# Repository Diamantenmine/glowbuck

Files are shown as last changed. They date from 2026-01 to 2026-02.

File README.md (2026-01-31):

# glowbuck
Glowbuck is a voltage converter and control board that allows you to power addressable LED strips with USB-C PD.

Together with [Firefly Luciferin](https://github.com/sblantipodi/firefly_luciferin), you can create your own ambilight that connects via USB-C to your computer and draws power from a USB-C PD power supply. Glowbuck is in no way associated with the linked project.


The left USB-C socket is used for data. The right socket shall be connected to a suitable USB-C PD supply. The spring-loaded connection terminal allows easy and safe connection to a 5 V addressable LED strip with, for example, SK6812 or WS2812B. The output current is measured with a 2 mOhm shunt. A shunt amplifier allows the integrated ESP32 S3 to measure the current flow and shut down the buck regulator when an unusually large current is detected.

## Quick Facts:
- Output: 5 V @ 10 A
- Input: 20 V @ 3 A. Via I2C, the microcontroller can reconfigure the PD controller and negotiate other voltage and current requirements for the input.
- Microcontroller: ESP32 S3
- Output current measurement with an integrated shunt

## Warning and Disclaimer

**Warning**: This project is in a alpha state and the hardware has not yet been tested.

This project is provided "as is" without warranty of any kind, either expressed or implied. The author makes no guarantees regarding the functionality, reliability, or suitability of this project for any particular purpose.
By using this project, you acknowledge and agree that:
- No liability is accepted for any damages, losses, or issues arising from the use or inability to use this project
- There is no guarantee that this project will work as intended or work at all
- The author shall not be held responsible for any direct, indirect, incidental, or consequential damages

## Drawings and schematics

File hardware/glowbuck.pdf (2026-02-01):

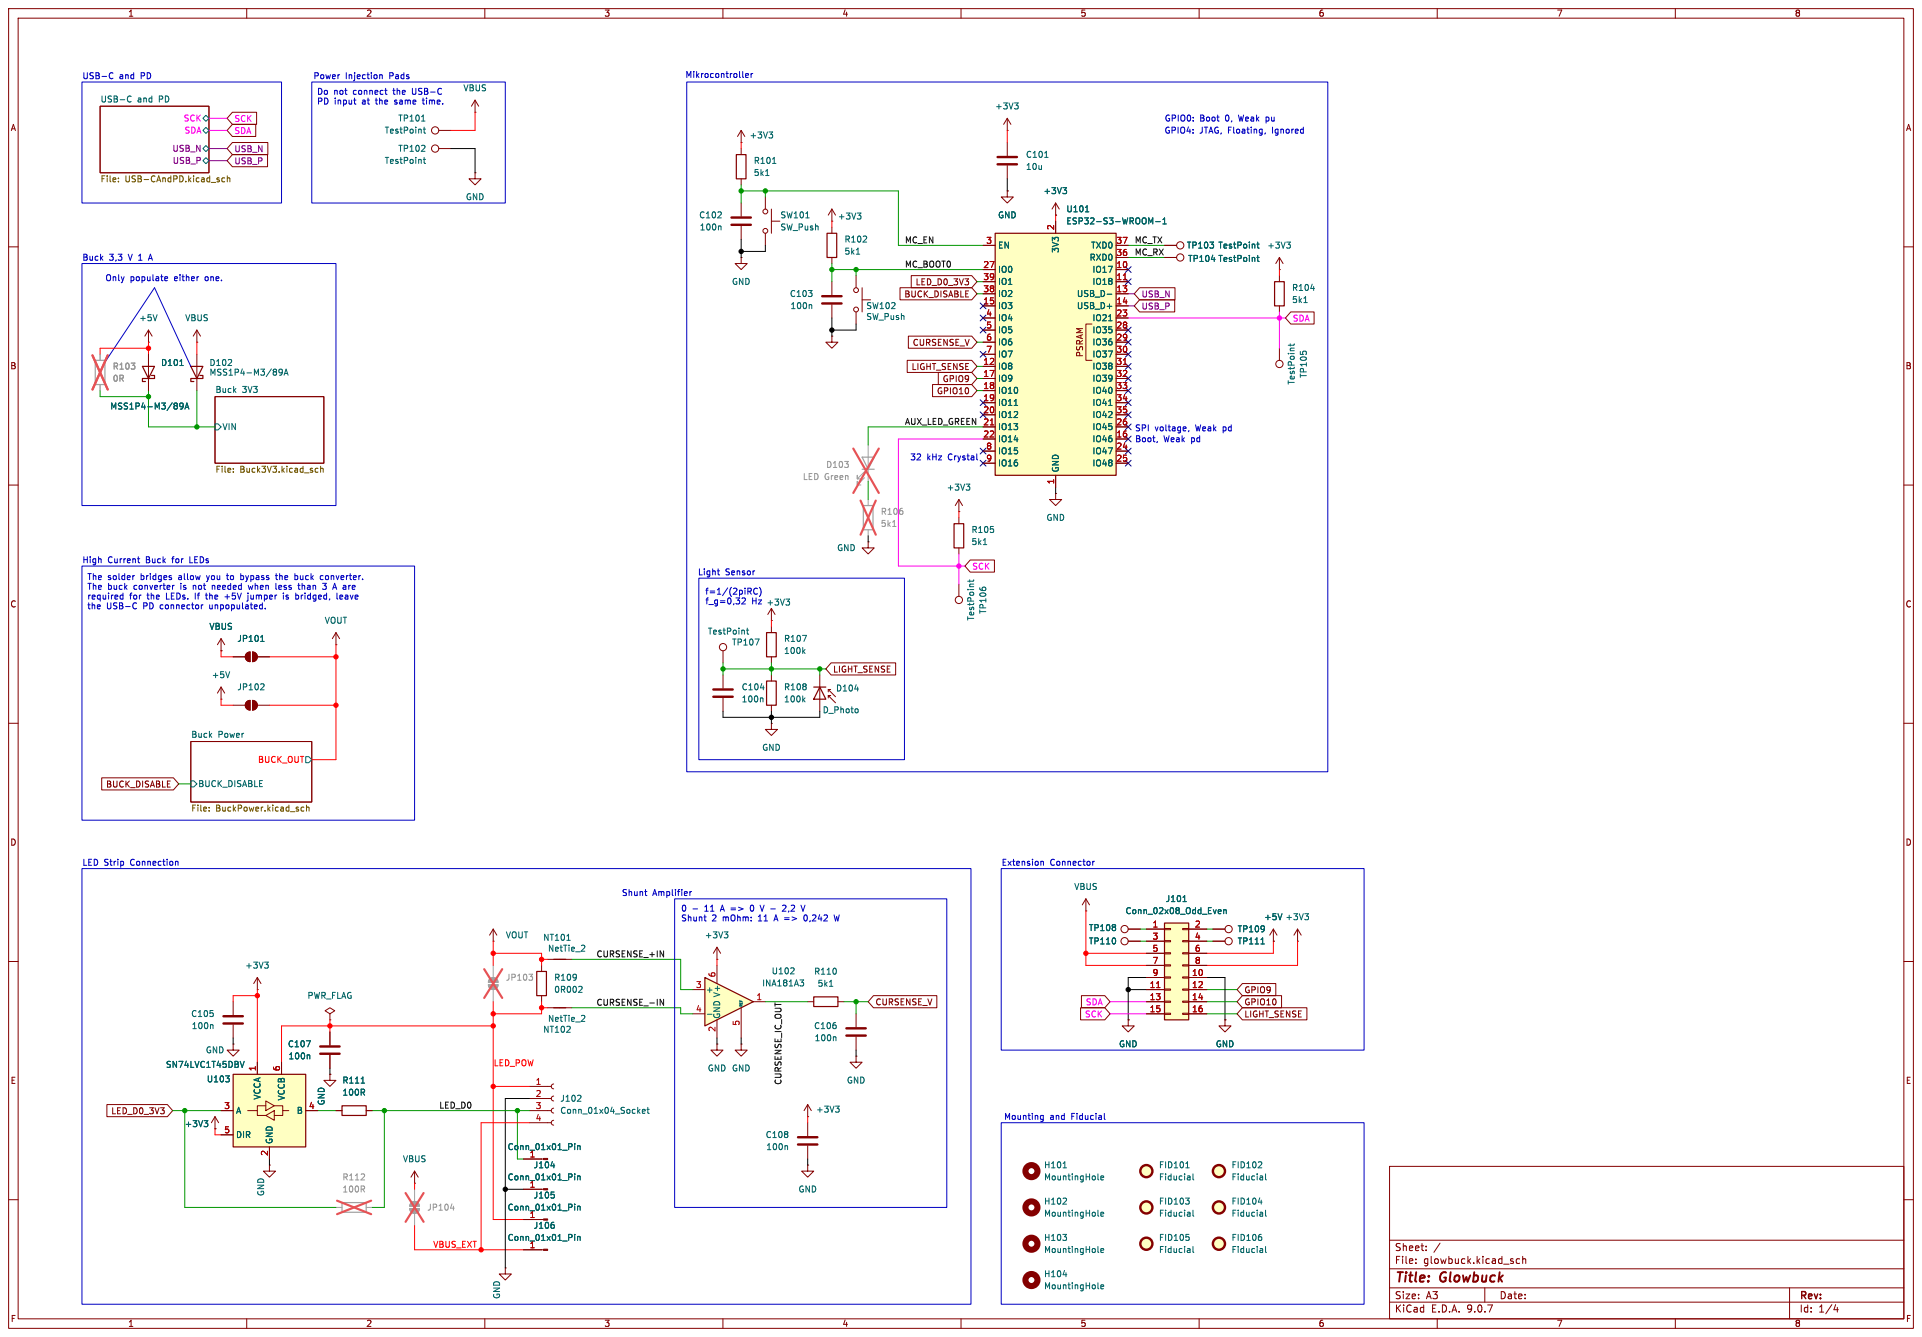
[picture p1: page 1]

File: USB-CAndPD.kicad_sch VIN

High Current Buck for LEDs

BUCK_OUT Buck Power File: BuckPower.kicad_sch

Shunt Amplifier LED Strip Connection

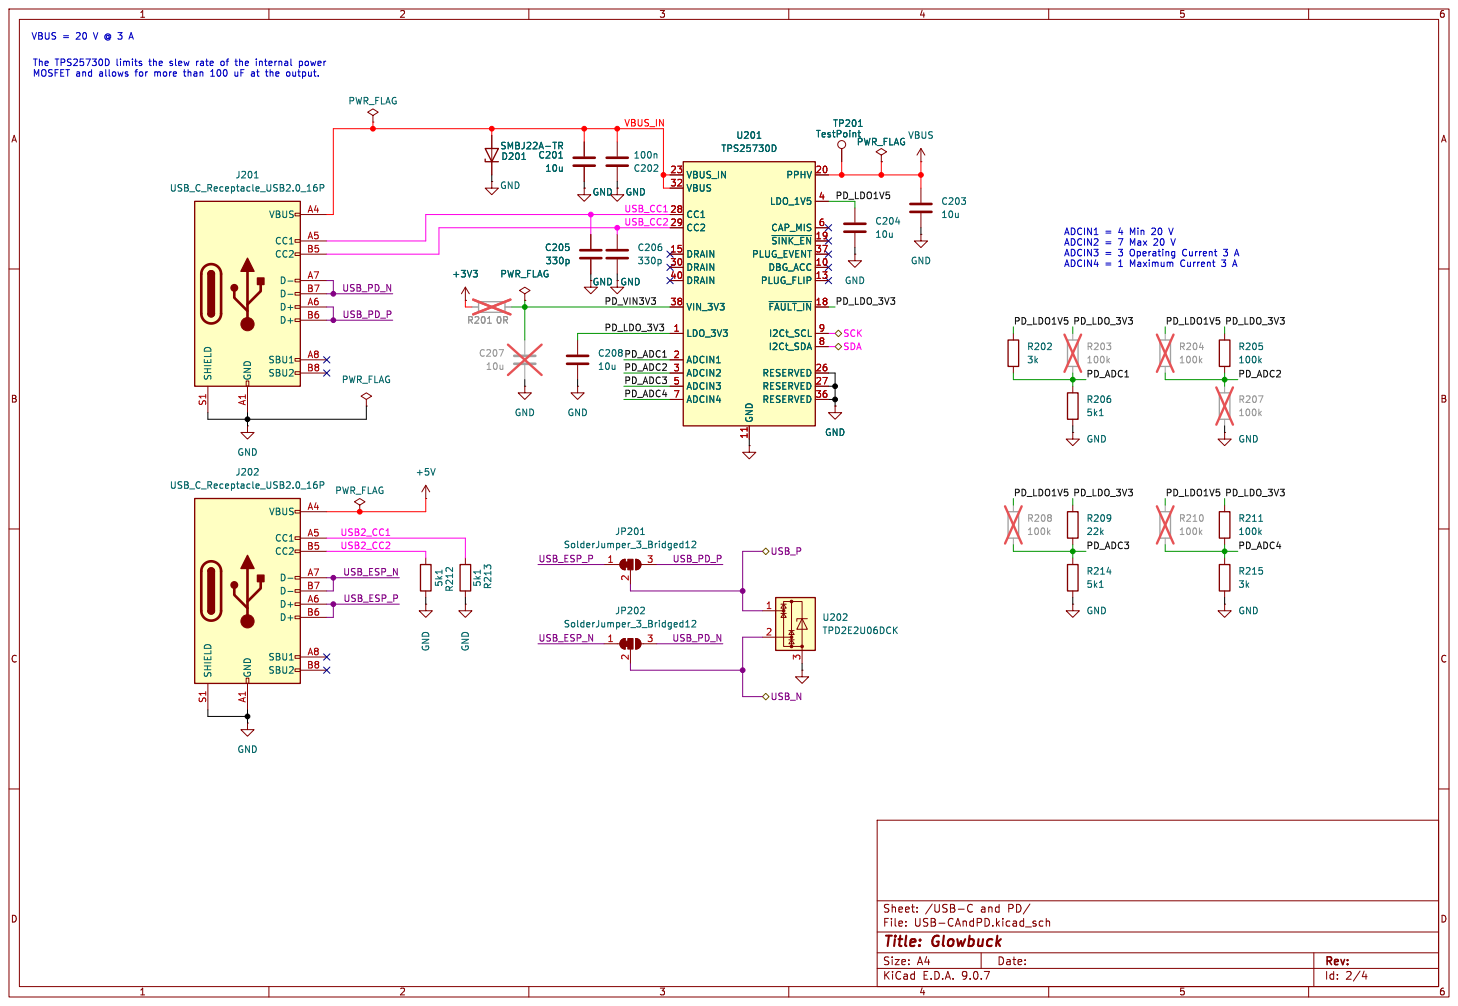
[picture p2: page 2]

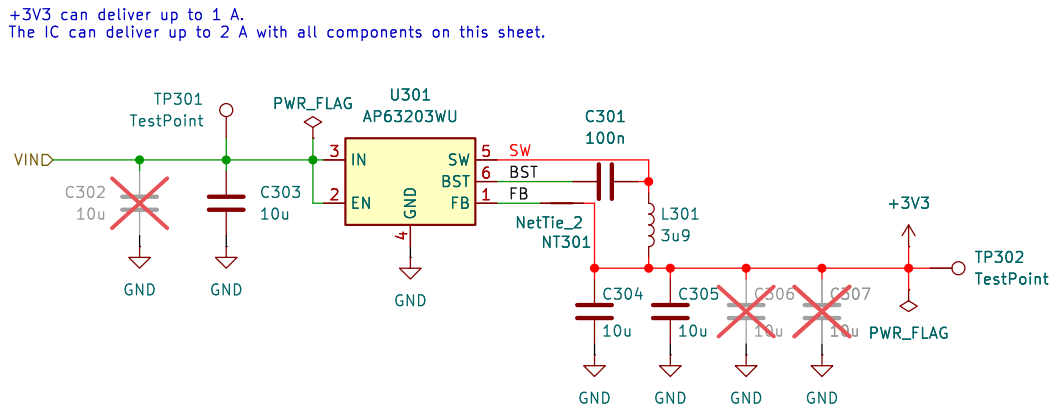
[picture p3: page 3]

4 SW 5 BST 6 FB 1 U301 AP63203WU GND GND

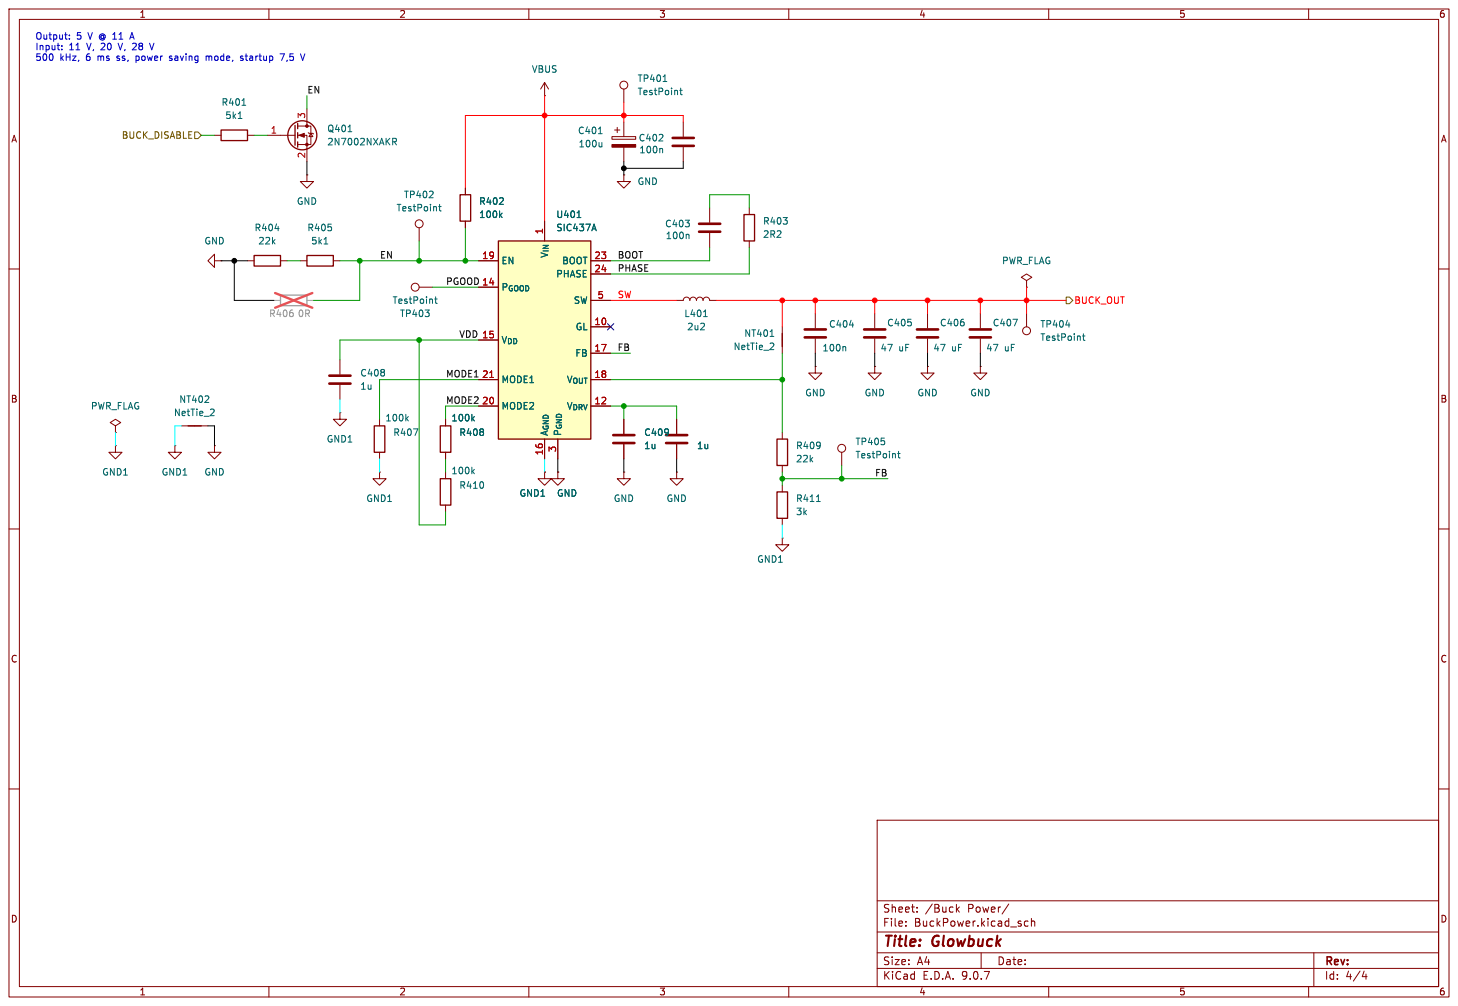
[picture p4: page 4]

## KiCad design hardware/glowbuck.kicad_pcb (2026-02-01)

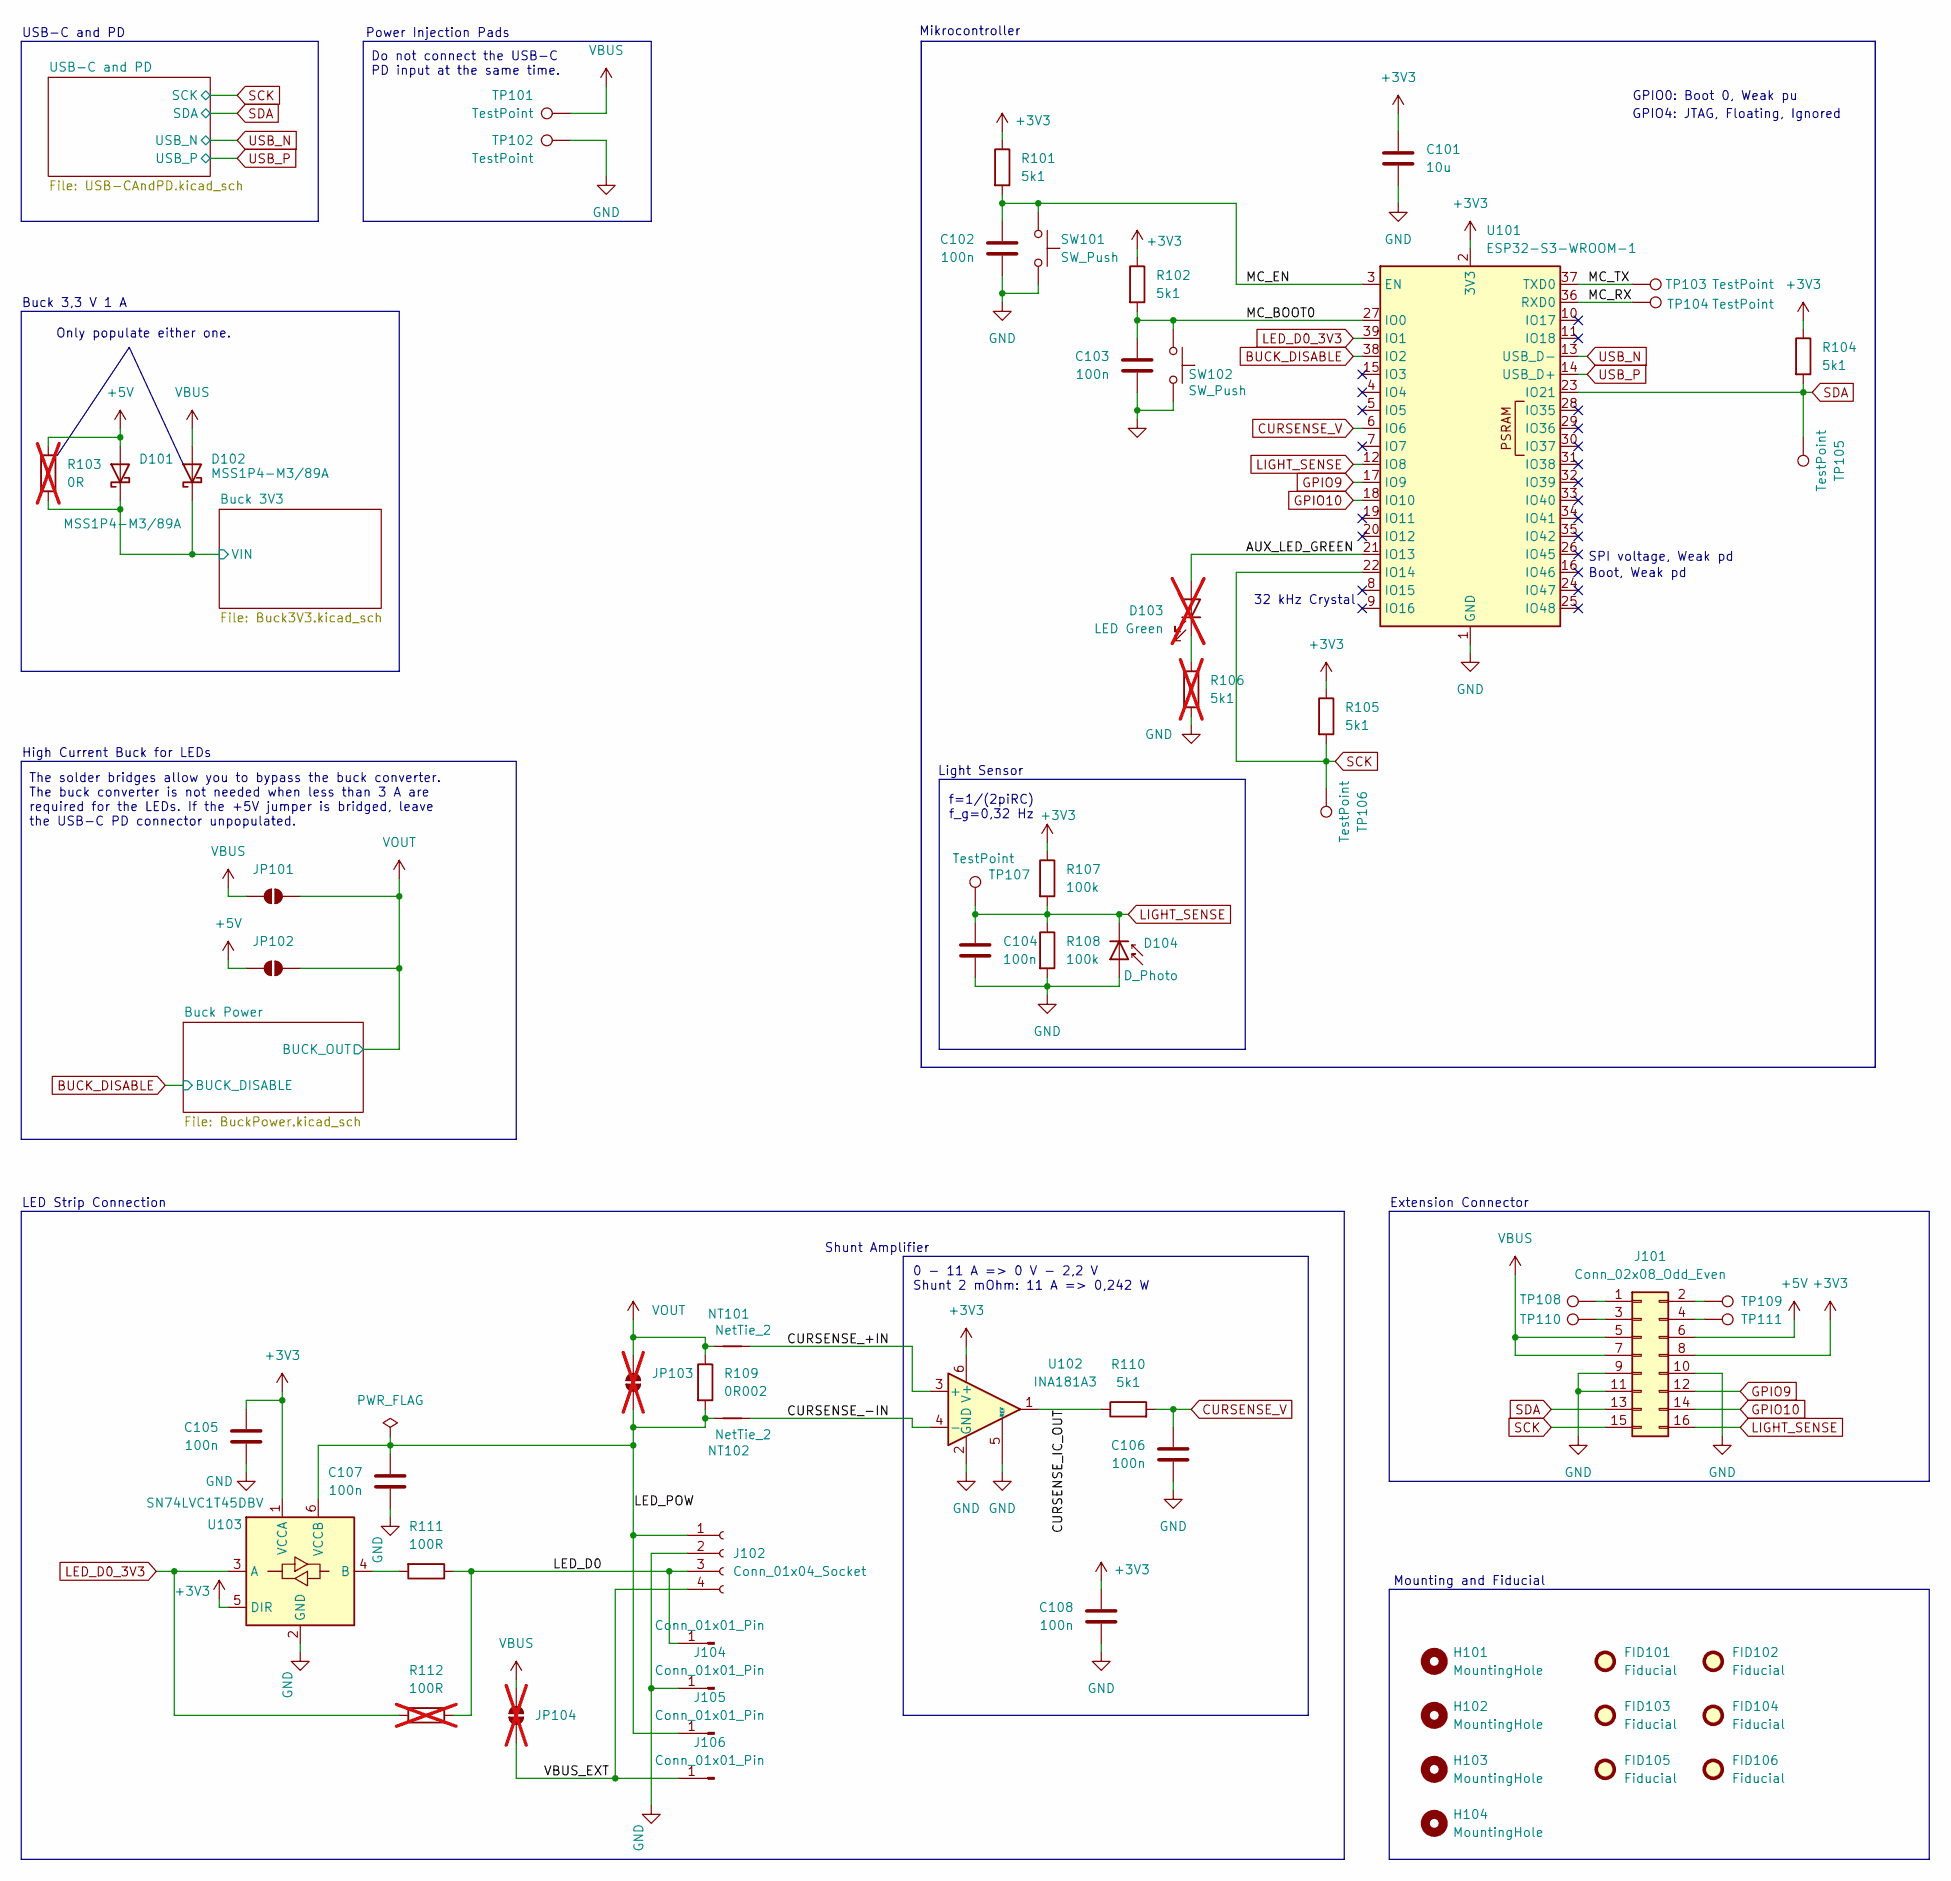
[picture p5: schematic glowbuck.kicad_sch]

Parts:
C101: 10u; C_0603_1608Metric; MouserNumber 187-CL10A106MA8NRNC
C102, C103, C104, C105, C106, C107, C108: 100n; C_0603_1608Metric; MouserNumber 187-CL10B104KB8WPND
D101, D102: MSS1P4-M3/89A; D_MicroSMP_AK; MouserNumber 625-MSS1P4-M3
D103: LED Green; LED_0603_1608Metric; MouserNumber 710-150060VS55040; not fitted
D104: D_Photo; D_1206_3216Metric; MouserNumber 743-IN-S126BTNPD
FID101, FID102, FID103, FID104, FID105, FID106: Fiducial; Fiducial_0.5mm_Mask1mm
H101, H102, H103, H104: MountingHole; MountingHole_2.2mm_M2_DIN965_Pad_TopBottom
J101: Conn_02x08_Odd_Even; PinHeader_2x08_P2.00mm_Vertical
J102: Conn_01x04_Socket; PTS 1,5_ 4-5,0-H; MouserNumber 651-1792889
J103: Conn_01x01_Pin; TestPoint_Pad_1.0x1.0mm
J104, J105, J106: Conn_01x01_Pin; TestPoint_Pad_3.0x3.0mm
JP101, JP102: SolderJumper_2_Open; SolderJumper_Open_HighCurrent
JP103, JP104: SolderJumper_2_Open; SolderJumper_Open_HighCurrent; not fitted
NT101, NT102: NetTie_2; NETTIE_0.3mm
R101, R102, R104, R105, R110: 5k1; R_0603_1608Metric; MouserNumber 603-RC0603FR-105K1L
R103: 0R; R_0603_1608Metric; MouserNumber 603-RC0603FR-130RL; not fitted
R106: 5k1; R_0603_1608Metric; MouserNumber 603-RC0603FR-105K1L; not fitted
R107, R108: 100k; R_0603_1608Metric; MouserNumber 603-RT0603FRE07100KL
R109: 0R002; R_0805_2012Metric; MouserNumber 71-WFC08052L000FE66
R111: 100R; R_0603_1608Metric; MouserNumber 603-RE0603FRE07100RL
R112: 100R; R_0603_1608Metric; MouserNumber 603-RE0603FRE07100RL; not fitted
SW101, SW102: SW_Push; PTS526_GPins_NoGround_2Pole; MouserNumber 611-PTS526SM20S21LFS
TP101, TP102: TestPoint; TestPoint_Pad_3.0x3.0mm
TP103, TP104, TP105, TP106, TP107, TP108, TP109, TP110, TP111: TestPoint; TestPoint_Pad_D1.0mm
U101: ESP32-S3-WROOM-1; MouserNumber 356-ESP32-S3WROOM1N4
U102: INA181A3; SOT-23-6; MouserNumber 595-INA181A3IDBVR
U103: SN74LVC1T45DBV; SOT-23-6; MouserNumber 595-74LVC1T45DBVRG4

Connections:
+3V3: C101.1, C105.1, C108.1, J101.8, R101.1, R102.1, R104.1, R105.1, R107.1, U101.2 (3V3), U102.6 (V+), U103.1 (VCCA), U103.5 (DIR); also elsewhere on the board
+5V: D101.2 (A), J101.6, JP102.1 (A), R103.2; also elsewhere on the board
/AUX_LED_GREEN: D103.2 (A), U101.21 (IO13)
/Buck 3V3/VIN: D101.1 (K), D102.1 (K), R103.1; also elsewhere on the board
/CURSENSE_+IN: NT101.1, U102.3 (+)
/CURSENSE_-IN: NT102.1, U102.4 (-)
/CURSENSE_IC_OUT: R110.1, U102.1
/LED_D0: J102.3, J103.1, R111.1, R112.1
/LED_POW: C107.1, J102.1, J105.1, JP103.1 (A), NT102.2, R109.2, U103.6 (VCCB)
/MC_BOOT0: C103.1, R102.2, SW102.1, U101.27 (IO0)
/MC_EN: C102.1, R101.2, SW101.1, U101.3 (EN)
/MC_RX: TP104.1, U101.36 (RXD0)
/MC_TX: TP103.1, U101.37 (TXD0)
/VBUS_EXT: J102.4, J106.1, JP104.1 (A)
BUCK_DISABLE: U101.38 (IO2); also elsewhere on the board
CURSENSE_V: C106.1, R110.2, U101.6 (IO6)
GND: C101.2, C102.2, C103.2, C104.2, C105.2, C106.2, C107.2, C108.2, D104.2 (A), J101.9, J101.10, J101.11, J102.2, J104.1, R106.2, R108.2, SW101.2, SW102.2, TP102.1, U101.1 (GND), U101.40 (GND), U101.41 (GND), U102.2 (GND), U102.5 (REF), U103.2 (GND); also elsewhere on the board
GPIO9: J101.12, U101.17 (IO9)
GPIO10: J101.14, U101.18 (IO10)
LED_D0_3V3: R112.2, U101.39 (IO1), U103.3 (A)
LIGHT_SENSE: C104.1, D104.1 (K), J101.16, R107.2, R108.1, TP107.1, U101.12 (IO8)
unnamed: D103.1 (K), R106.1
unnamed: J101.1, TP108.1
unnamed: J101.2, TP109.1
unnamed: J101.3, TP110.1
unnamed: J101.4, TP111.1
unnamed: R111.2, U103.4 (B)
SCK: J101.15, R105.2, TP106.1, U101.22 (IO14); also elsewhere on the board
SDA: J101.13, R104.2, TP105.1, U101.23 (IO21); also elsewhere on the board
USB_N: U101.13 (USB_D-); also elsewhere on the board
USB_P: U101.14 (USB_D+); also elsewhere on the board
VBUS: D102.2 (A), J101.5, J101.7, JP101.1 (A), JP104.2 (B), TP101.1; also elsewhere on the board
VOUT: JP101.2 (B), JP102.2 (B), JP103.2 (B), NT101.2, R109.1; also elsewhere on the board

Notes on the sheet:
Only populate either one.
SPI voltage, Weak pd
Do not connect the USB-C PD input at the same time.
Mikrocontroller
Light Sensor
Power Injection Pads
GPIO4: JTAG, Floating, Ignored
Buck 3,3 V 1 A
Mounting and Fiducial
0 - 11 A => 0 V - 2,2 V Shunt 2 mOhm: 11 A => 0,242 W
GPIO0: Boot 0, Weak pu
Extension Connector
USB-C and PD
Boot, Weak pd
Shunt Amplifier
The solder bridges allow you to bypass the buck converter. The buck converter is not needed when less than 3 A are required for the LEDs. If the +5V jumper is bridged, leave the USB-C PD connector unpopulated.
32 kHz Crystal
f=1/(2piRC) f_g=0,32 Hz
LED Strip Connection
High Current Buck for LEDs

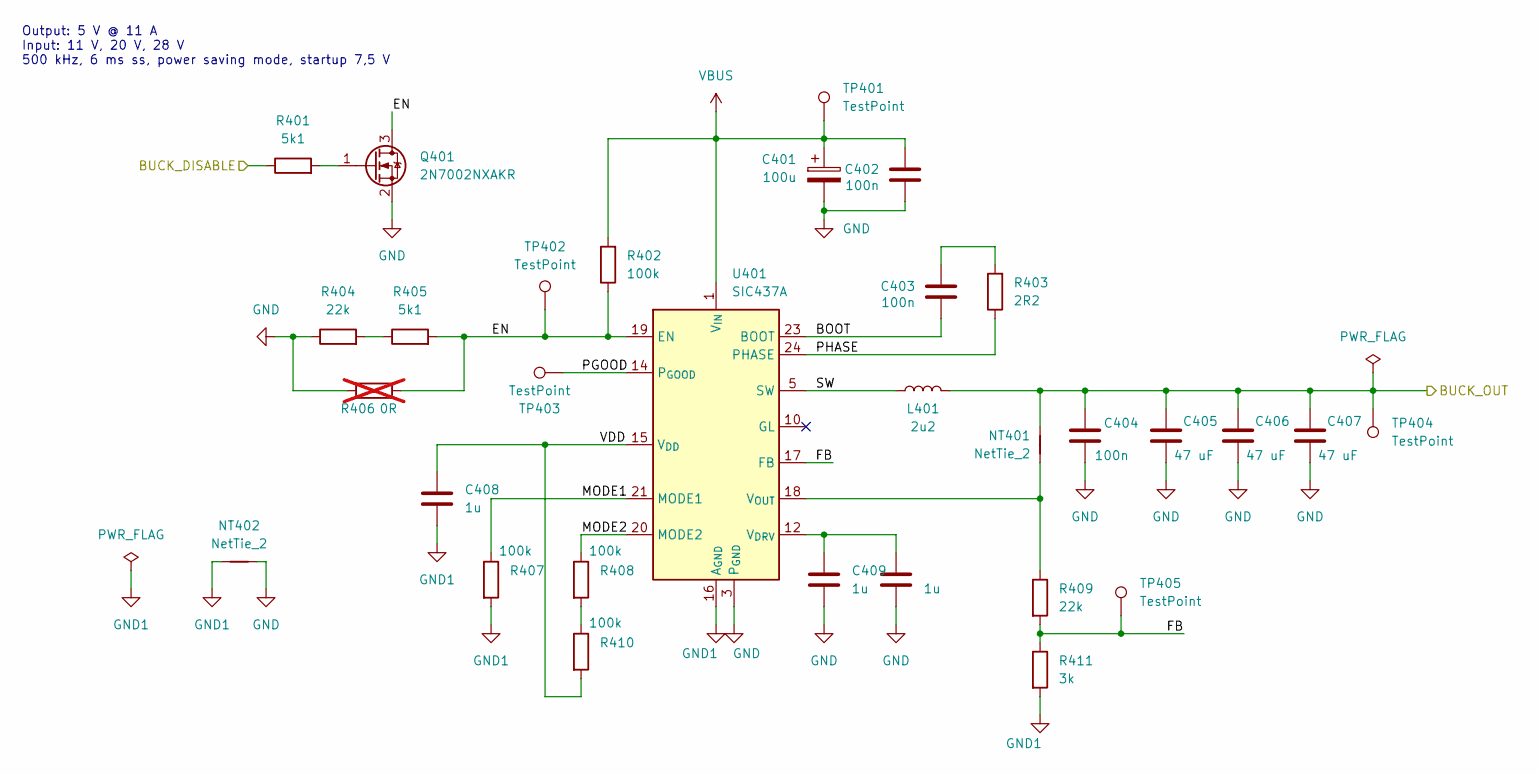
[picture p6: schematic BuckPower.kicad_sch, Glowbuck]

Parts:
C401: 100u; CP_Elec_8x10; MouserNumber 647-PCZ1V101MCL6GS
C402, C403, C404: 100n; C_0603_1608Metric; MouserNumber 187-CL10B104KB8WPND
C405, C406, C407: 47 uF; C_1210_3225Metric; MouserNumber 81-GRM32ER71A476KE5L
C408, C409, C410: 1u; C_0603_1608Metric; MouserNumber 187-CL10B105KA8NFNC
L401: 2u2; L_Vishay_IHLP-6767; MouserNumber 70-IHLP6767GZER2R2M0
NT401: NetTie_2; NETTIE_0.2mm
NT402: NetTie_2; NETTIE_0.3mm
Q401: 2N7002NXAKR; SOT-23-3; MouserNumber 771-2N7002NXAKR
R401, R405: 5k1; R_0603_1608Metric; MouserNumber 603-RC0603FR-105K1L
R402, R407, R408, R410: 100k; R_0603_1608Metric; MouserNumber 603-RT0603FRE07100KL
R403: 2R2; R_0603_1608Metric; MouserNumber 71-CRCW0603-2.2-E3
R404, R409: 22k; R_0603_1608Metric; MouserNumber 603-RT0603DRE0722KL
R406: 0R; R_0603_1608Metric; MouserNumber 603-RC0603FR-130RL; not fitted
R411: 3k; R_0603_1608Metric; MouserNumber 603-RC0603FR-133KL
TP401, TP402, TP403, TP404, TP405: TestPoint; TestPoint_Pad_D1.0mm
U401: SIC437A; Vishay_PowerPAK_MLP44-24L_ThermalVias; MouserNumber 78-SIC437AED-T1-GE3

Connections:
/Buck Power/BOOT: C403.2, U401.23 (BOOT)
/Buck Power/EN: Q401.3 (D), R402.1, R405.2, R406.1, TP402.1, U401.19 (EN)
/Buck Power/FB: R409.2, R411.1, TP405.1, U401.17 (FB)
/Buck Power/MODE1: R407.1, U401.21 (MODE1)
/Buck Power/MODE2: R408.1, U401.20 (MODE2)
/Buck Power/PGOOD: TP403.1, U401.14 (P_{GOOD})
/Buck Power/PHASE: R403.1, U401.24 (PHASE)
/Buck Power/SW: L401.1, U401.5 (SW), U401.6 (SW), U401.7 (SW), U401.8 (SW), U401.9 (SW)
/Buck Power/VDD: C408.1, R410.2, U401.15 (V_{DD})
BUCK_DISABLE: R401.1; also elsewhere on the board
GND: C401.2, C402.2, C404.2, C405.2, C406.2, C407.2, C409.1, C410.2, NT402.2, Q401.2 (S), R404.1, R406.2, U401.3 (P_{GND}), U401.4 (P_{GND}), U401.13 (P_{GND}), U401.27 (P_{GND}); also elsewhere on the board
GND1: C408.2, NT402.1, R407.2, R411.2, U401.16 (A_{GND}), U401.25 (A_{GND})
unnamed: C403.1, R403.2
unnamed: Q401.1 (G), R401.2
unnamed: R404.2, R405.1
unnamed: R408.2, R410.1
unnamed: C409.2, C410.1, U401.12 (V_{DRV})
unnamed: NT401.2, R409.1, U401.18 (V_{OUT})
VBUS: C401.1, C402.1, R402.2, TP401.1, U401.1 (V_{IN}), U401.2 (V_{IN}), U401.22 (V_{IN}), U401.26 (V_{IN}); also elsewhere on the board
VOUT: C404.1, C405.1, C406.1, C407.1, L401.2, NT401.1, TP404.1; also elsewhere on the board

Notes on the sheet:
Output: 5 V @ 11 A Input: 11 V, 20 V, 28 V 500 kHz, 6 ms ss, power saving mode, startup 7,5 V

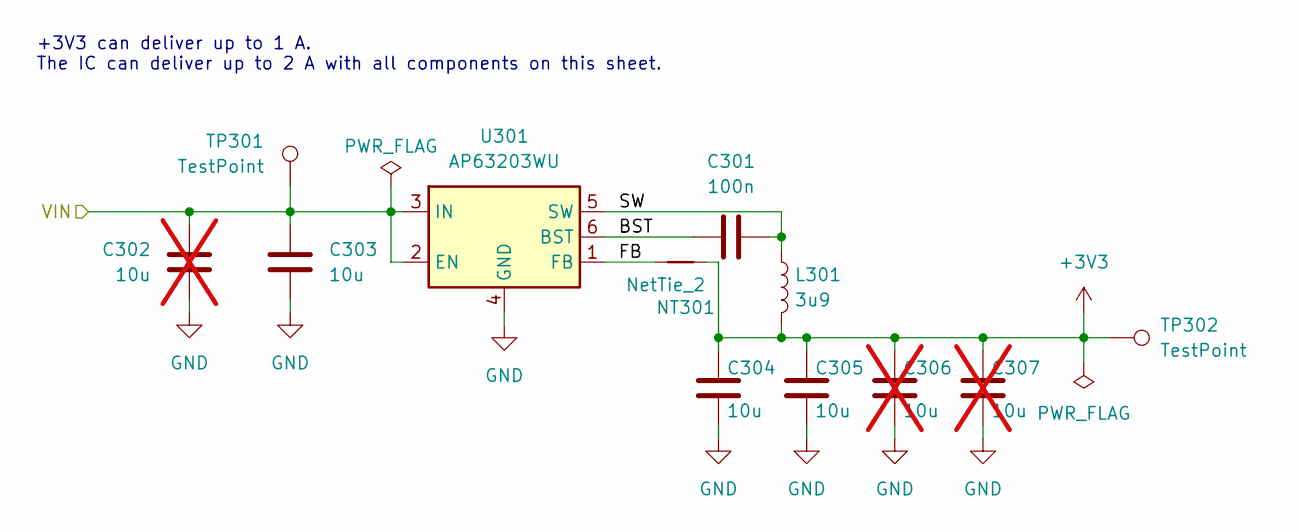
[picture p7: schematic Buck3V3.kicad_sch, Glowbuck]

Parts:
C301: 100n; C_0603_1608Metric; MouserNumber 187-CL10B104KB8WPND
C302: 10u; C_1210_3225Metric; MouserNumber 187-CL32B106KBJNNNE; not fitted
C303: 10u; C_1210_3225Metric; MouserNumber 187-CL32B106KBJNNNE
C304, C305: 10u; C_0603_1608Metric; MouserNumber 187-CL10A106MA8NRNC
C306, C307: 10u; C_0603_1608Metric; MouserNumber 187-CL10A106MA8NRNC; not fitted
L301: 3u9; BOURNS_SRR7045; MouserNumber 652-SRR7045-3R9M
NT301: NetTie_2; NETTIE_0.3mm
TP301, TP302: TestPoint; TestPoint_Pad_D1.5mm
U301: AP63203WU; TSOT-23-6; MouserNumber 621-AP63203WU-7

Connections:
+3V3: C304.2, C305.2, C306.2, C307.2, L301.2, NT301.2, TP302.1; also elsewhere on the board
/Buck 3V3/BST: C301.1, U301.6 (BST)
/Buck 3V3/FB: NT301.1, U301.1 (FB)
/Buck 3V3/SW: C301.2, L301.1, U301.5 (SW)
/Buck 3V3/VIN: C302.1, C303.2, TP301.1, U301.2 (EN), U301.3 (IN); also elsewhere on the board
GND: C302.2, C303.1, C304.1, C305.1, C306.1, C307.1, U301.4 (GND); also elsewhere on the board

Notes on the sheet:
+3V3 can deliver up to 1 A. The IC can deliver up to 2 A with all components on this sheet.

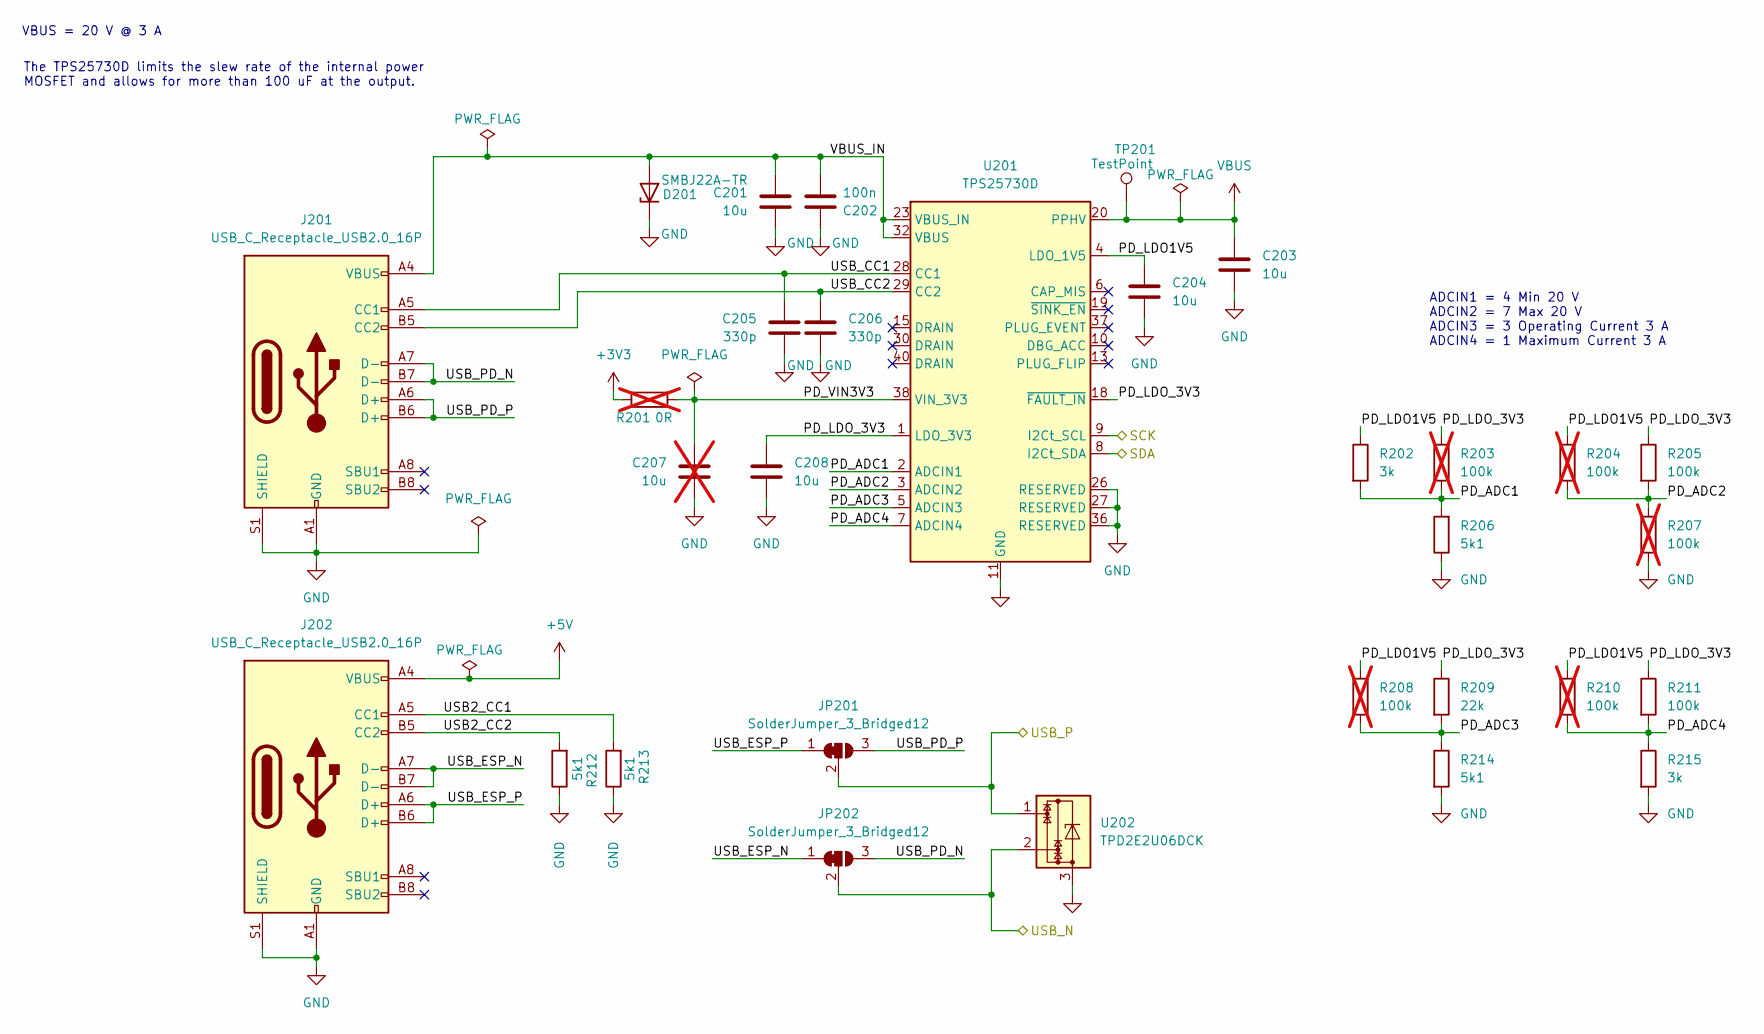
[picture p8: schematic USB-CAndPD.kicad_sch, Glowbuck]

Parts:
C201, C203: 10u; C_1210_3225Metric; MouserNumber 187-CL32B106KBJNNNE
C202: 100n; C_0603_1608Metric; MouserNumber 187-CL10B104KB8WPND
C204, C208: 10u; C_0603_1608Metric; MouserNumber 187-CL10A106MA8NRNC
C205, C206: 330p; C_0603_1608Metric; MouserNumber 80-C0603C331K5R
C207: 10u; C_0603_1608Metric; MouserNumber 187-CL10A106MA8NRNC; not fitted
D201: SMBJ22A-TR; D_SMB; MouserNumber 511-SMBJ22A
J201, J202: USB_C_Receptacle_USB2.0_16P; USB_C_Receptacle_GCT_USB4105-xx-A_16P_TopMnt_Horizontal; MouserNumber 640-USB4105-GF-A
JP201, JP202: SolderJumper_3_Bridged12; SolderJumper_123_0603
R201: 0R; R_0603_1608Metric; MouserNumber 603-RC0603FR-130RL; not fitted
R202, R215: 3k; R_0603_1608Metric; MouserNumber 603-RC0603FR-133KL
R203, R204, R207, R208, R210: 100k; R_0603_1608Metric; MouserNumber 603-RT0603FRE07100KL; not fitted
R205, R211: 100k; R_0603_1608Metric; MouserNumber 603-RT0603FRE07100KL
R206, R212, R213, R214: 5k1; R_0603_1608Metric; MouserNumber 603-RC0603FR-105K1L
R209: 22k; R_0603_1608Metric; MouserNumber 603-RT0603DRE0722KL
TP201: TestPoint; TestPoint_Pad_D1.5mm
U201: TPS25730D; Texas_REF0038A_WQFN-38-2EP_6x4mm_P0.4; MouserNumber 595-TPS25730DREFR
U202: TPD2E2U06DCK; SOT-323_SC-70; MouserNumber 595-TPD2E2U06QDCKRQ1

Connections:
+3V3: R201.2; also elsewhere on the board
+5V: J202.A4 (VBUS), J202.A9 (VBUS), J202.B4 (VBUS), J202.B9 (VBUS); also elsewhere on the board
/USB-C and PD/PD_ADC1: R202.2, R203.2, R206.2, U201.2 (ADCIN1)
/USB-C and PD/PD_ADC2: R204.2, R205.2, R207.1, U201.3 (ADCIN2)
/USB-C and PD/PD_ADC3: R208.2, R209.2, R214.1, U201.5 (ADCIN3)
/USB-C and PD/PD_ADC4: R210.2, R211.2, R215.1, U201.7 (ADCIN4)
/USB-C and PD/PD_LDO1V5: C204.2, R202.1, R204.1, R208.1, R210.1, U201.4 (LDO_1V5)
/USB-C and PD/PD_LDO_3V3: C208.2, R203.1, R205.1, R209.1, R211.1, U201.1 (LDO_3V3), U201.18 (~FAULT_IN)
/USB-C and PD/PD_VIN3V3: C207.2, R201.1, U201.38 (VIN_3V3)
/USB-C and PD/USB2_CC1: J202.A5 (CC1), R213.2
/USB-C and PD/USB2_CC2: J202.B5 (CC2), R212.2
/USB-C and PD/USB_CC1: C205.1, J201.A5 (CC1), U201.28 (CC1)
/USB-C and PD/USB_CC2: C206.1, J201.B5 (CC2), U201.29 (CC2)
/USB-C and PD/USB_ESP_N: J202.A7 (D-), J202.B7 (D-), JP202.1 (A)
/USB-C and PD/USB_ESP_P: J202.A6 (D+), J202.B6 (D+), JP201.1 (A)
/USB-C and PD/USB_PD_N: J201.A7 (D-), J201.B7 (D-), JP202.3 (B)
/USB-C and PD/USB_PD_P: J201.A6 (D+), J201.B6 (D+), JP201.3 (B)
/USB-C and PD/VBUS_IN: C201.2, C202.2, D201.2 (A), J201.A4 (VBUS), J201.A9 (VBUS), J201.B4 (VBUS), J201.B9 (VBUS), U201.23 (VBUS_IN), U201.32 (VBUS)
GND: C201.1, C202.1, C203.1, C204.1, C205.2, C206.2, C207.1, C208.1, D201.1 (K), J201.A1 (GND), J201.A12 (GND), J201.B1 (GND), J201.B12 (GND), J201.S1 (SHIELD), J202.A1 (GND), J202.A12 (GND), J202.B1 (GND), J202.B12 (GND), J202.S1 (SHIELD), R206.1, R207.2, R212.1, R213.1, R214.2, R215.2, U201.11 (GND), U201.12 (GND), U201.14 (GND), U201.16 (GND), U201.17 (GND), U201.26 (RESERVED), U201.27 (RESERVED), U201.31 (GND), U201.34 (GND), U201.36 (RESERVED), U201.39 (GND), U202.3; also elsewhere on the board
SCK: U201.9 (I2Ct_SCL); also elsewhere on the board
SDA: U201.8 (I2Ct_SDA); also elsewhere on the board
USB_N: JP202.2 (C), U202.2; also elsewhere on the board
USB_P: JP201.2 (C), U202.1; also elsewhere on the board
VBUS: C203.2, TP201.1, U201.20 (PPHV); also elsewhere on the board

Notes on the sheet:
The TPS25730D limits the slew rate of the internal power MOSFET and allows for more than 100 uF at the output.
ADCIN1 = 4 Min 20 V ADCIN2 = 7 Max 20 V ADCIN3 = 3 Operating Current 3 A ADCIN4 = 1 Maximum Current 3 A
VBUS = 20 V @ 3 A

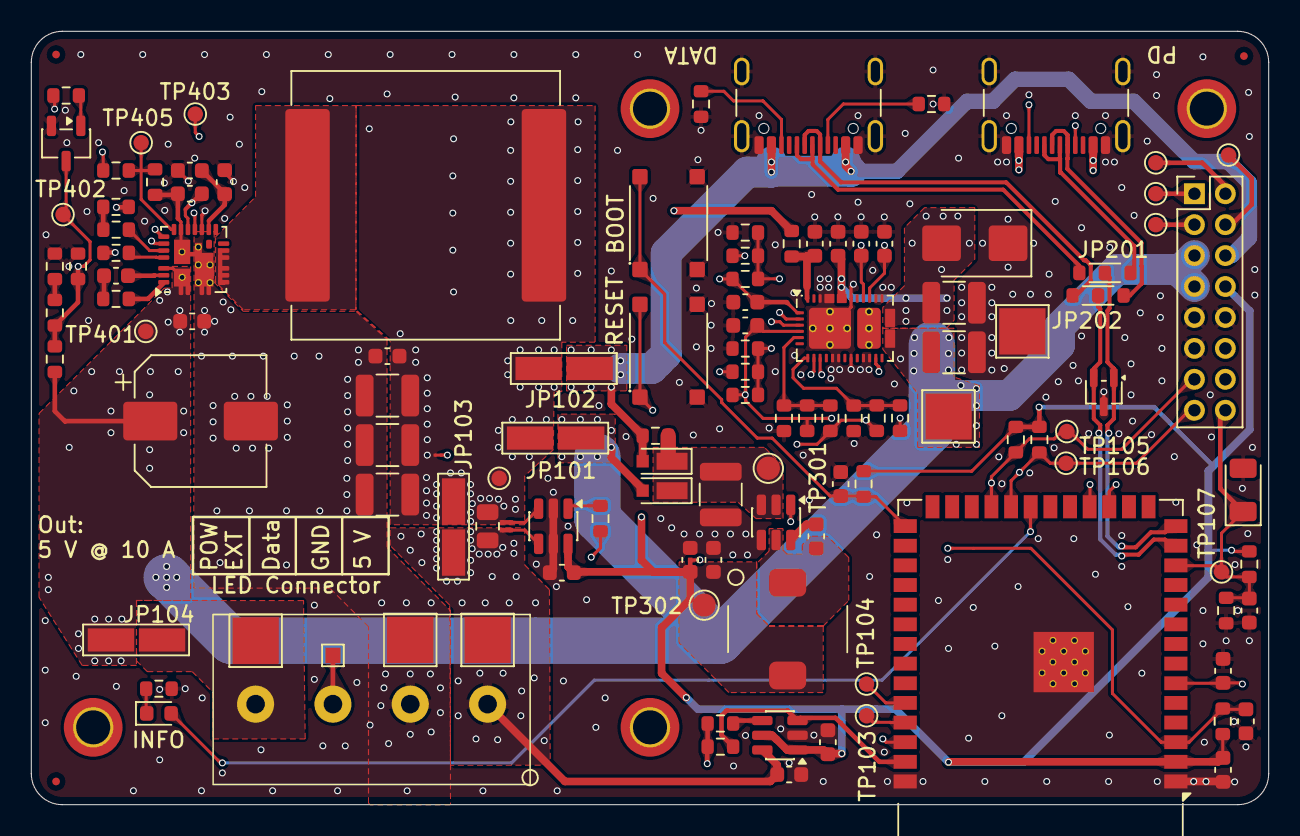
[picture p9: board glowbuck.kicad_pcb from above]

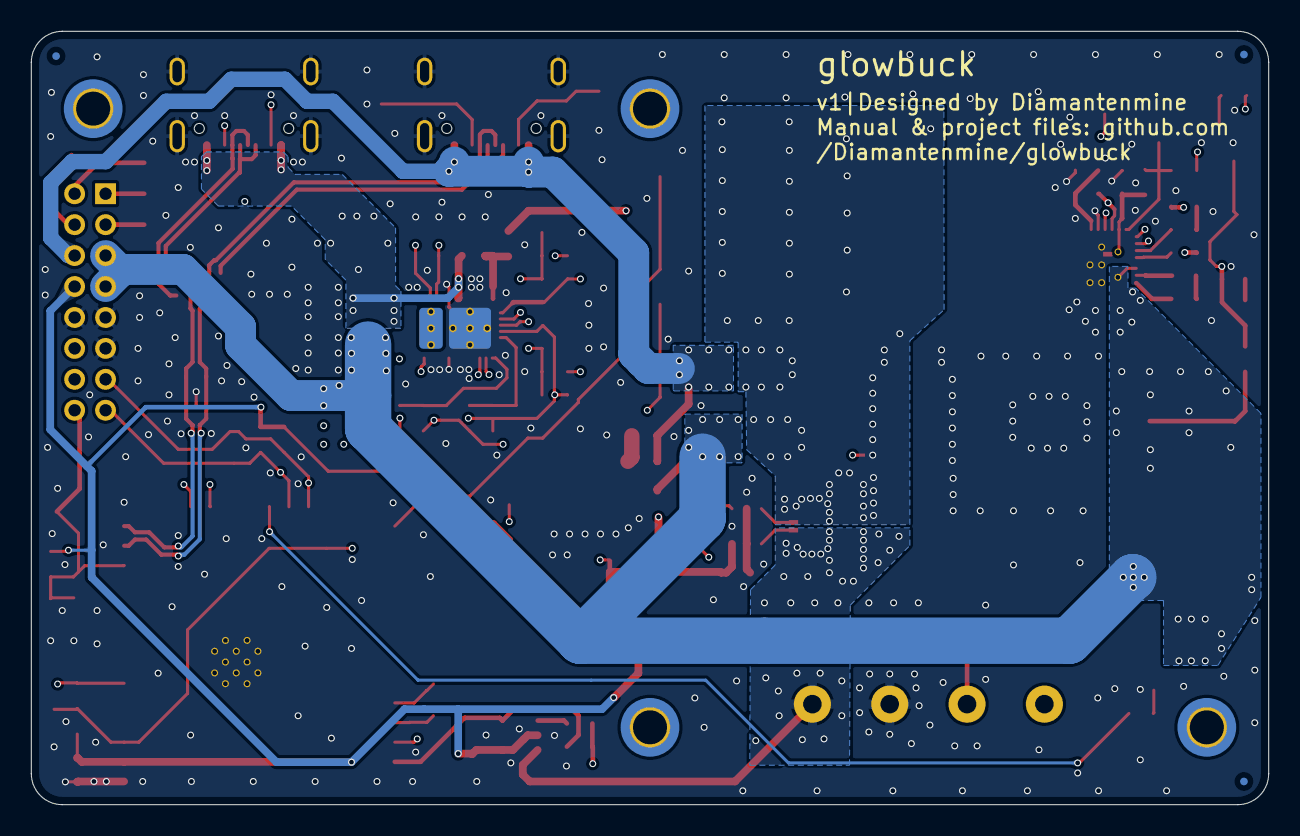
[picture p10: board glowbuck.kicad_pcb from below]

Board: 4 copper layers, 80.0 x 50.0 mm, 132 parts (3 on the bottom side), 68 nets.

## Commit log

2026-01-08 Schaltplan erstellt
    [Buck3V3.kicad_sch, BuckPower.kicad_sch, LogicLevelConverter.kicad_sch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]
2026-01-12 Optimized BOM and added netties
    [Buck3V3.kicad_sch, BuckPower.kicad_sch, LogicLevelConverter.kicad_sch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]
2026-01-14 Spring terminal, finalising PD settings, checking buck 10 A
    [BuckPower.kicad_sch, USB-CAndPD.kicad_sch, glowbuck.kicad_sch]
2026-01-14 Changed footprints to non hand solder option
    [Buck3V3.kicad_sch, BuckPower.kicad_sch, USB-CAndPD.kicad_sch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]
2026-01-17 Colored nets and added optional current measurement
    [Buck3V3.kicad_sch, BuckPower.kicad_sch, USB-CAndPD.kicad_sch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]
2026-01-18 Set up PCB setting
    [glowbuck.kicad_pcb]
2026-01-18 Global labels, explanation texts, fix spring connector
    [Buck3V3.kicad_sch, BuckPower.kicad_sch, USB-CAndPD.kicad_sch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]
2026-01-21 Layout Stecker final, USB done, buck wip
    [Buck3V3.kicad_sch, BuckPower.kicad_sch, USB-CAndPD.kicad_sch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]
2026-01-25 Layout in progress. I2C done
    [Buck3V3.kicad_sch, BuckPower.kicad_sch, USB-CAndPD.kicad_sch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]
2026-01-27 Fixed drc errors
    [glowbuck.kicad_pcb, glowbuck.kicad_sch]
2026-01-31 Fixed drc problems
    [glowbuck.kicad_pcb]
2026-01-31 Exchanged shunt resistor
    [glowbuck.kicad_pcb, glowbuck.kicad_sch]
2026-01-31 Added ManufacturerNumber for every item and fixed bom errors
    [Buck3V3.kicad_sch, BuckPower.kicad_sch, USB-CAndPD.kicad_sch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]
2026-01-31 Connected VBUS to the free phoenix connector pin
    [glowbuck.kicad_pcb, glowbuck.kicad_sch]
2026-01-31 Thermal reliefes
    [USB-CAndPD.kicad_sch, glowbuck.kicad_pcb]
2026-01-31 Exchanged 5k11 with 5k1 part number
    [BuckPower.kicad_sch, USB-CAndPD.kicad_sch, glowbuck.kicad_pcb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]
2026-01-31 Adjusted product numbers and silkscreen for ordernumber
    [glowbuck.kicad_pcb, glowbuck.kicad_sch]
2026-02-01 Optimized via silkscreen overlap and added pdf circuit diagram
    [glowbuck.kicad_pcb]
